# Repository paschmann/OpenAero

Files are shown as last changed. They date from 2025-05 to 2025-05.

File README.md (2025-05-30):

# OpenAero - A Open Source 3D-Printed Bicycle Accessory Mounting System

## Overview

The goal is to develop a modular mounting system for bicycle accessories — ranging from water bottle holders and lights to phone and cycling computers. Partially inspired by Gridfinity, this system provides a base platform and is intended to be stackable. The motivation behind the definition and open source nature of this project is to encourage community-driven design and innovation in the triathlon, and cycling space.

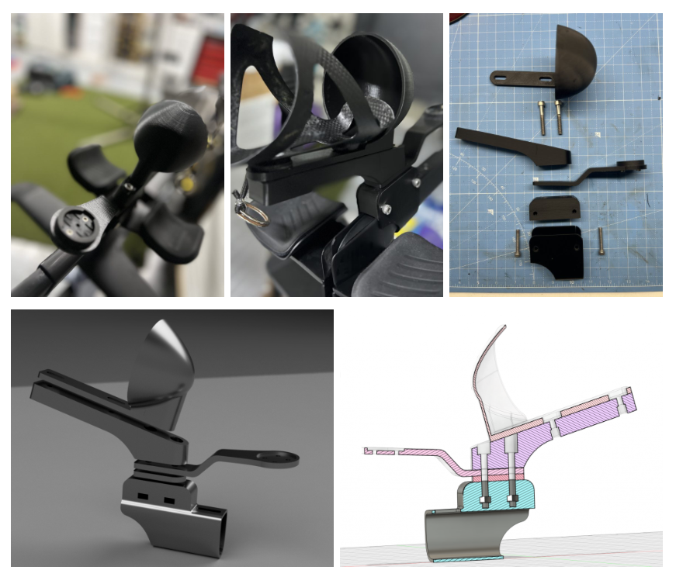
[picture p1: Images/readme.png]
Grid


### Concept

The fundamental concept is to create both specific and generic base mounts per bicycle model, whereby accessories can then be attached to the base mount using a standard pattern and design allowing you to mix and match your accessory "stack" depending on your needs. Accessories are not specific to a bike or model and are rather modular, and depend on your set of requirements.

A base mount could be the seat post, handlebars, aerobars, frame or bottle cage.

### Design

Standard

Standardized rectangular base mounting system of 21mm x 47mm with two M6 bolt pattern 25mm apart in the center. 

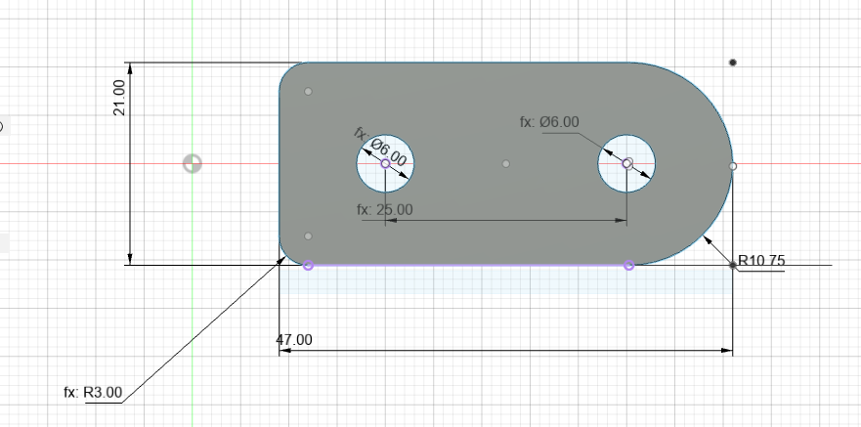
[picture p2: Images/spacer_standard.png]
Spacer


Small

A small rectangular base mounting system of 12mm x 23.5mm with one M5 bolt in the center. 

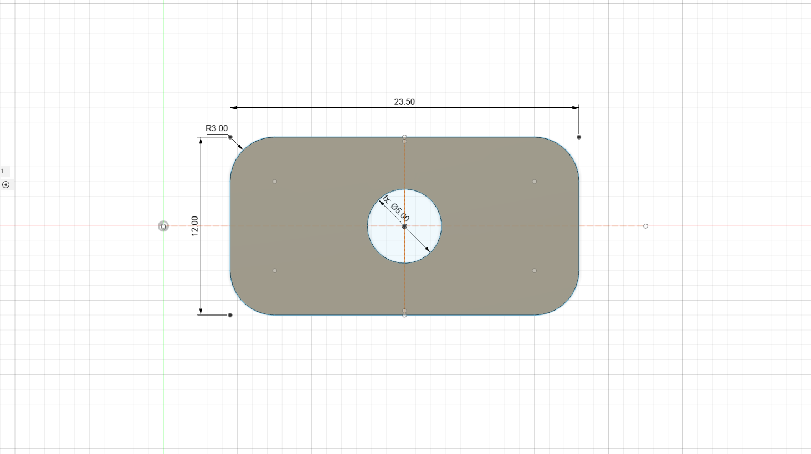
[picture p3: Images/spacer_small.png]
Spacer


### Printing

All bases and parts are intended to be 3D printed (many require supports), and most components require mounting hardware to be installed after printing is complete and is fairly straight forward. In all cases we recommend stainless steel, using locknut (blue) and torquing according to your manufacturers recommendations, especially when mounting the base or accessories to carbon fiber.

### Installation

In order to calculate the bolt lengths required, add up each accessories "Bolt Depth Required" on the accessories readme page.

Example:
You would like to mount a water bottle and computer mount on a Canyon Speedmax CF SLX.

Step 1. Select the Bike Mount required
Canyon Speedmax CF SLX Slide v1 - Bolt Depth Required: 12.5mm

Step 2. Select the bottle mount required
Bottle - Bolt Depth Required: 12.5mm

Step 3. Select the computer mount required
Computer Mount - Bolt Depth Required: 5mm

Step 4. Measure the height of your M6 bolt you purchased
Bolt - +- 5mm

Total bolt length: 35mm

Extremely important: ALWAYS assemble the base and accessories before installing them on your bike, to ensure no bolts or hardware will scratch or protrude into your bike frame or mounting hardware.

### ⚠️ Risk Disclaimer
This project and its associated files are provided for informational and non-commercial purposes only. All components are intended for mounting lightweight bicycle accessories only (e.g., lights, bottles, small electronics). These parts are not designed, tested, or approved for any load-bearing or safety-critical applications involving human weight or structural support.

By using or modifying these designs, you agree to assume all risks and responsibilities. The developer(s) and contributors are not liable for any injury, damage, or loss arising from the use or misuse of these components.

Always use common sense and test parts thoroughly in safe conditions before deploying them on a bicycle.

## Want to help?

Read our [Contributing Guide](CONTRIBUTING.md)

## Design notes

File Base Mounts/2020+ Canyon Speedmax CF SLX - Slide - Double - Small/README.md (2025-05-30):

# 2020+ Canyon Speedmax CF SLX - Slide Double Sided - Small v1

## Overview

Provides a base mount for a the Canyon GP0226 Aerobar and can be installed by disassembling the aerobars, this is relatively easy if you are using wireless blips. The accepts two small accessories such as computer mounts or a GoPro. Untested with water bottles, etc.

### Design Model
Bike used to design the part: 2025 Canyon Speedmax CF SLX

### Specs
Height: 63mm
Width: 27mm
Length: 55mm

### Accessory Mount Specs
Base Mount: 12mm x 23.5mm (Small)
Bolt Depth Required: 6mm

### Hardware Required

1 x 20mm M4 Hex Bolt (Button head suggested)
1 x ~ 4mm M4 Washer

### Installation Notes

This version of the Bike Mount is slide based which implies you need to remove the Speedmax extensions, and reuse of the existing mount holes with a new longer bolt.

NB: Be sure that the accessory bolts do not protrude through the base and come into contact of your bars.

### Design

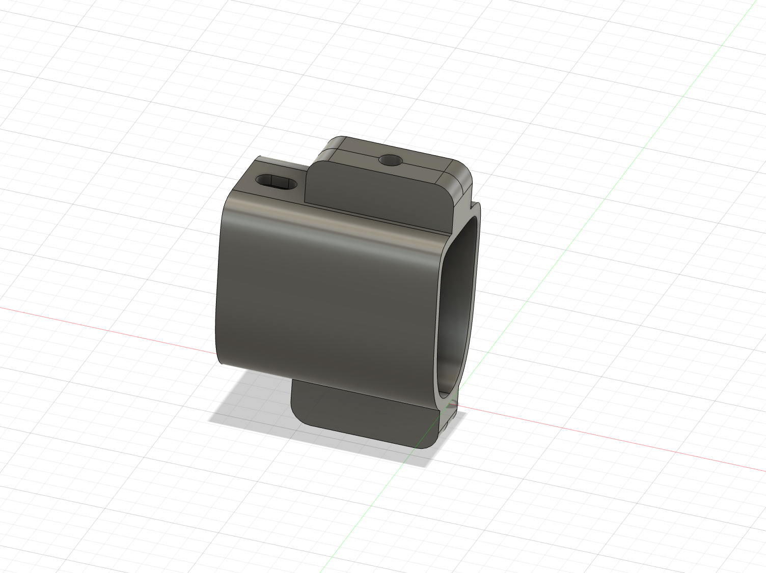
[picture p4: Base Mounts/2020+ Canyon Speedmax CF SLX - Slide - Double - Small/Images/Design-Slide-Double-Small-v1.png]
Design Screenshot


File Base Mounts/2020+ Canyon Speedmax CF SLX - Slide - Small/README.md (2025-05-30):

# 2020+ Canyon Speedmax CF SLX - Slide Small v1

## Overview

Provides a base mount for a the Canyon GP0226 Aerobar and can be installed by disassembling the aerobars, this is relatively easy if you are using wireless blips. The accepts small accessories such as computer mounts or a GoPro. Untested with water bottles, etc.

### Design Model
Bike used to design the part: 2025 Canyon Speedmax CF SLX

### Specs
Height: 57mm
Width: 27mm
Length: 55mm

### Accessory Mount Specs
Base Mount: 12mm x 23.5mm (Small)
Bolt Depth Required: 6mm

### Hardware Required

1 x 20mm M4 Hex Bolt (Button head suggested)
1 x ~ 4mm M4 Washer

### Installation Notes

This version of the Bike Mount is slide based which implies you need to remove the Speedmax extensions, and reuse of the existing mount holes with a new longer bolt.

NB: Be sure that the accessory bolts do not protrude through the base and come into contact of your bars.

### Design

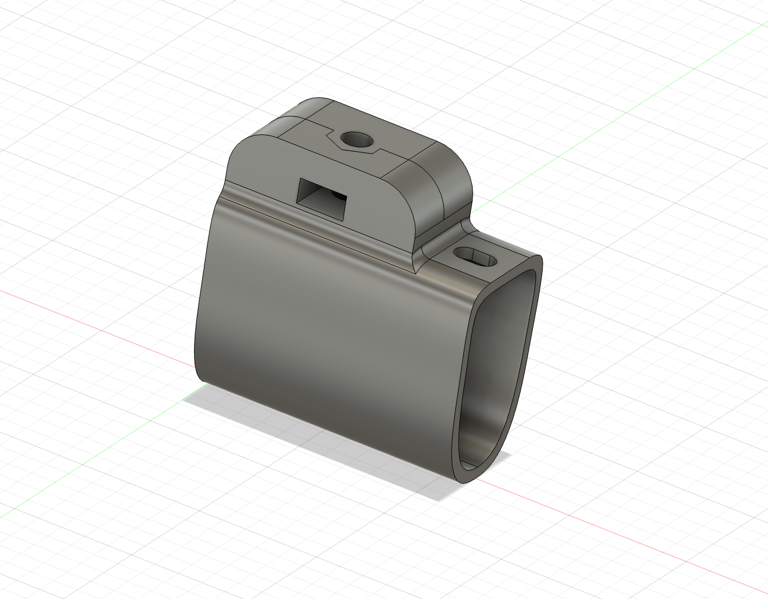
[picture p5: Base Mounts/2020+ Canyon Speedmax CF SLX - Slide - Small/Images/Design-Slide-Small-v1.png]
Design Screenshot


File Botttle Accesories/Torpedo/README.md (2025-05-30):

# Computer Mount

## Overview

Provides a torpedo shaped bottle cover for the OpenAero system, this is intended to provide a aerodynamic benefit for a water bottle between your arms.

### Specs
Height: 5mm\
Total Height: ~ 29mm\
Width: ~ 38mm\
Length: 148mm

### Accessory Mount Spec
Base Mount: Standard Bottle Cage
Bolt Length Required: 5mm

### Hardware Required

None

Note: Your water bottle cage bolts should be long enough to extend through this base which is 5mm thick.

### Installation Notes

Provides some adjustability (+- 10mm) to slide forward and backward to cater for various bottle cages.

### Design

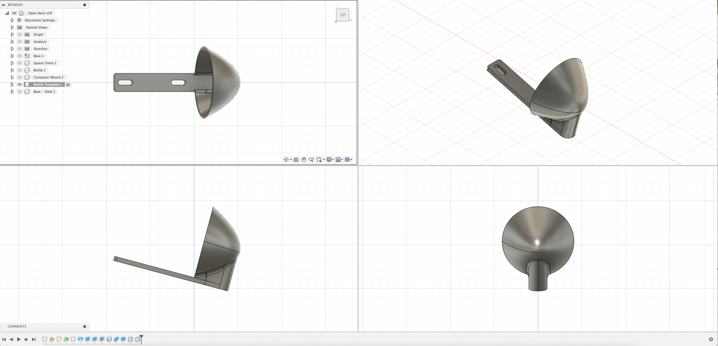
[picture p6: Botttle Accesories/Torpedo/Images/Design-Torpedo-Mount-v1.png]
Design Screenshot


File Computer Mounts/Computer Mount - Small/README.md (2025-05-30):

# Computer Mount - Small

## Overview

Provides a computer mount for the OpenAero system, and is raised slightly to provide access to any mounting or holes beneath the accessory. Requires a computer mount insert to be printed or purchased.

### Specs
Height: 5mm\
Total Height: ~ 36mm\
Width: ~ 36mm\
Length: 36mm

### Accessory Mount Spec
Base Mount: 12mm x 23.5mm (Small)\
Bolt Length Required: 10mm

### Hardware Required
1 x M5 Bolt
1 x Computer insert (e.g. Garmin, Wahoo, Hammerhead)\
2 x M3 bolts to attach computer insert onto accessory.\
2 x M3 Heat inserts (M3x5x6)

### Installation Notes

None

### Design

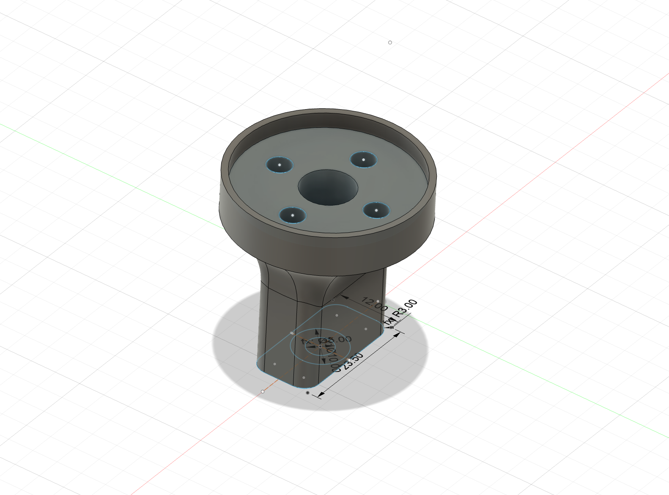
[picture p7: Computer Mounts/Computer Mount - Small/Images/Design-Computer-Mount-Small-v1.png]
Design Screenshot


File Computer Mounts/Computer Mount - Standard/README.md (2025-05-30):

# Computer Mount - Standard

 ### 🛑 Currently has an issue with being too flexible and could break quite easily. Currently being re-designed.

## Overview

Provides a computer mount for the OpenAero system, and is raised slightly to provide access to any mounting or holes beneath the accessory. Requires a computer mount insert to be printed or purchased.

### Specs
Height: 5mm\
Total Height: ~ 29mm\
Width: ~ 38mm\
Length: 148mm

### Accessory Mount Spec
Base Mount: 21mm x 47mm (Standard)\
Bolt Length Required: 5mm

### Hardware Required
1 x Computer insert (e.g. Garmin, Wahoo, Hammerhead)\
2 x M2 bolts to attach computer insert onto accessory.\

### Installation Notes

None

### Design

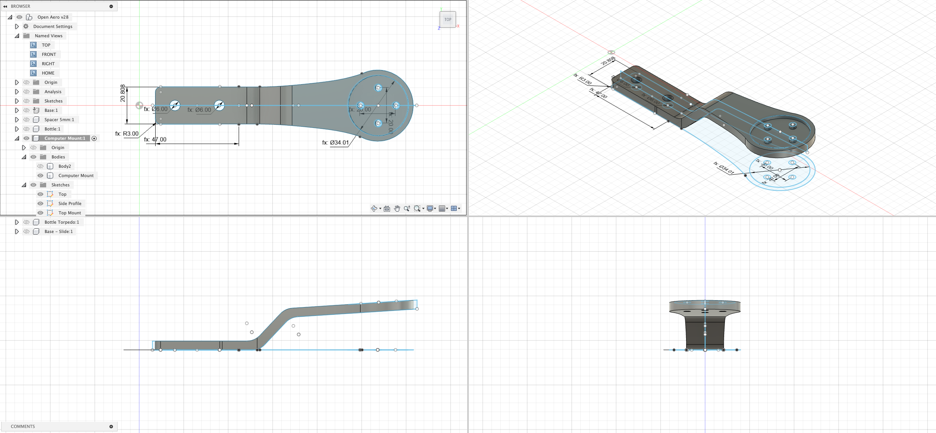
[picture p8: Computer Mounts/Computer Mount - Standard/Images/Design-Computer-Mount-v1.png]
Design Screenshot


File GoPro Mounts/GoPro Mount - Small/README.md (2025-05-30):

# GoPro Mount - Small

## Overview

Provides a small GoPro mount for the OpenAero system.

### Specs
Total Height: ~ 29mm\
Width: ~ 38mm\
Length: 148mm

### Accessory Mount Spec
Base Mount: 12mm x 32.5mm (Small)\
Bolt Length Required: 5mm

### Hardware Required
1 x M5 bolt
1 x M5 Nut

### Installation Notes

None

### Design

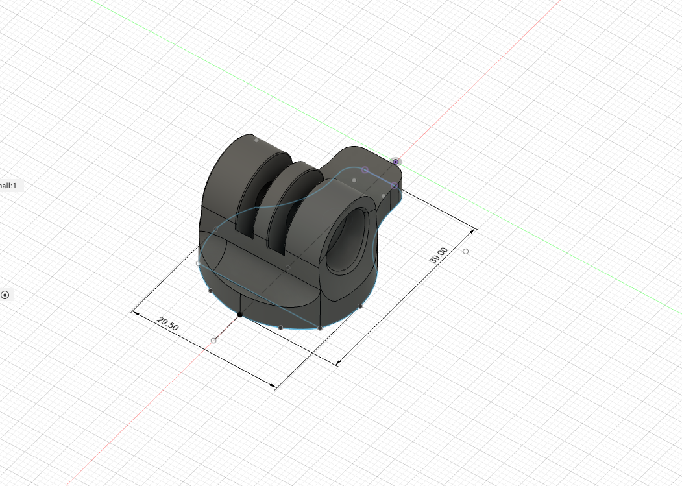
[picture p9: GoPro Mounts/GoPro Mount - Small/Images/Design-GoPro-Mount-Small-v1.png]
Design Screenshot


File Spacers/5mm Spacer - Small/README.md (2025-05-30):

# Spacer - 5mm - Small

## Overview

Provides a small 5mm spacer for the OpenAero design system, intended to raise the height of any accessory.

### Specs

Height: 5mm\
Width: 12mm\
Length: 32.5mm\

### Accessory Mount Spec

Base Mount: 12mm x 32.5mm (Small)\
Bolt Length Required: 5mm\

### Hardware Required
None

### Installation Notes
None

### Design
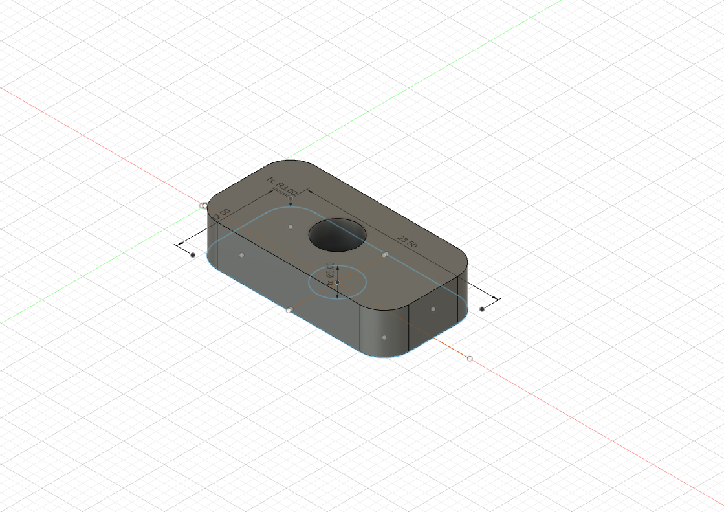
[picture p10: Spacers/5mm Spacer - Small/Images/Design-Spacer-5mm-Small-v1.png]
Design Screenshot


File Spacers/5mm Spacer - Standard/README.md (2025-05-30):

# Spacer - 5mm - Standard

## Overview

Provides a 5mm spacer for the OpenAero design system, intended to raise the height of any accessory.

### Specs

Height: 5mm\
Width: 21mm\
Length: 47mm\

### Accessory Mount Spec

Base Mount: 21mm x 47mm (Standard)\
Bolt Length Required: 5mm\

### Hardware Required
None

### Installation Notes
None

### Design
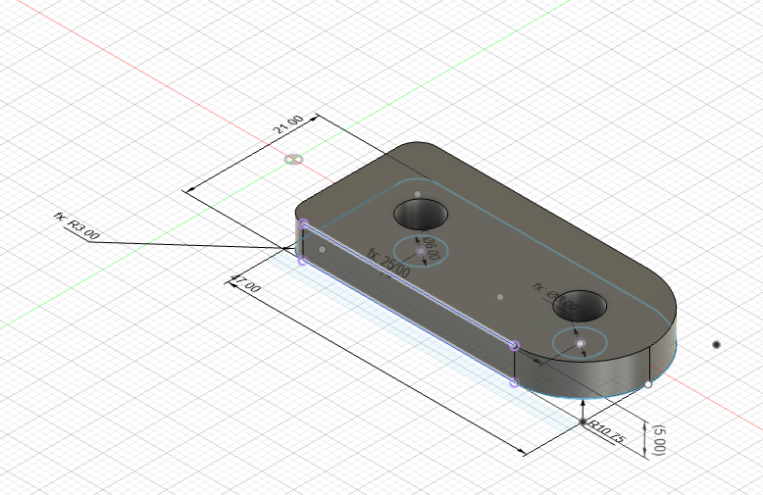
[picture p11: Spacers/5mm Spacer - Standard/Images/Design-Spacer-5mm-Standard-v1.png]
Design Screenshot


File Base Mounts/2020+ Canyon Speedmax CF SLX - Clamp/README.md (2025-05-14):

# 2020+ Canyon Speedmax CF SLX - Clamp Version 1

## Overview

Provides a base mount for a the Canyon GP0226 Aerobar and can be installed without disassembling the aerobars.

### Design Model
Bike used to design the part: 2025 Canyon Speedmax CF SLX

### Specs
Height: 24mm
Width:
Length:

### Accessory Mount Specs
Base Mount: 21mm x 47mm (Standard)
Bolt Depth Required: 12.5mm

### Hardware Required

2 x 30mm M5 Button Head Hex Bolt
2 x 3.8mm M5 Nuts

### Installation Notes

This version of the Bike Mount is clamp based which implies you do not need to remove the Speedmax extensions and can simply be bolted on. We recommend applying some tape to the mount area to improve grip and stability. Ne sure not to over tighten bolts (suggested torque, as for most carbon parts) is 5Nm.

NB: Be sure that the accessory bolts do not protrude through the base and come into contact of your bars.

### Design

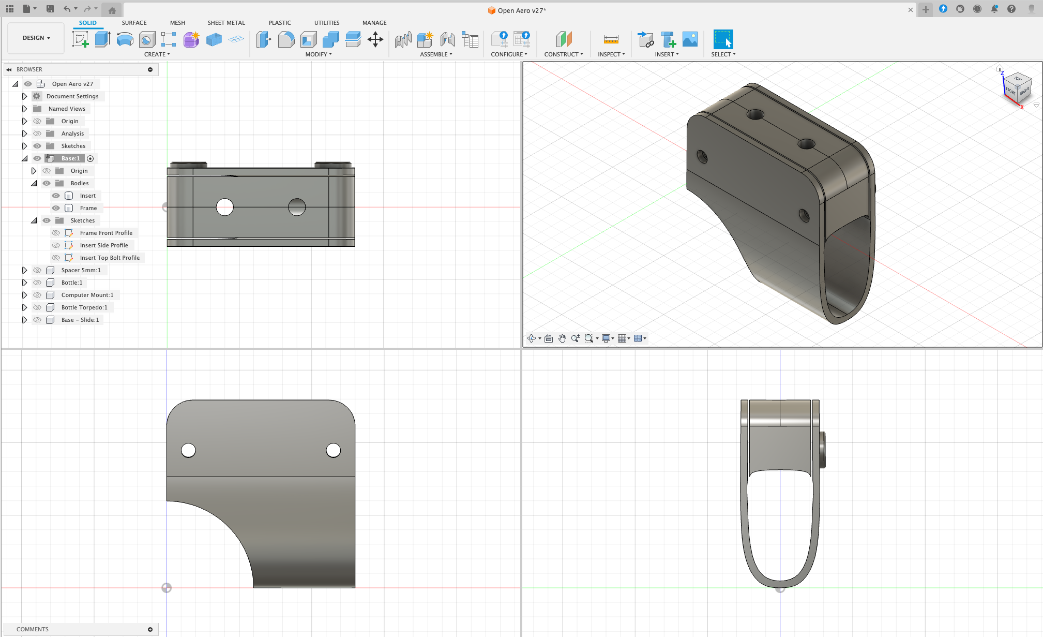
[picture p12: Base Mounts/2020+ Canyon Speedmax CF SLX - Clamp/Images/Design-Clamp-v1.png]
Design Screenshot


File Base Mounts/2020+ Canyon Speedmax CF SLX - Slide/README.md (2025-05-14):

# 2020+ Canyon Speedmax CF SLX - Slide Version 1

## Overview

Provides a base mount for a the Canyon GP0226 Aerobar and can be installed be disassembling the aerobars, this is relatively easy if you are using wireless blips. 

### Design Model
Bike used to design the part: 2025 Canyon Speedmax CF SLX

### Specs
Height: 24mm
Width:
Length:

### Accessory Mount Specs
Base Mount: (Standard) 21mm x 47mm
Bolt Depth Required: 12.5mm

### Hardware Required

1 x 20mm M4 Hex Bolt (Button head suggested)
1 x ~ 4mm M4 Washer

### Installation Notes

This version of the Bike Mount is slide based which implies you need to remove the Speedmax extensions, and reuse of the existing mount holes with a new longer bolt.

NB: Be sure that the accessory bolts do not protrude through the base and come into contact of your bars.

### Design

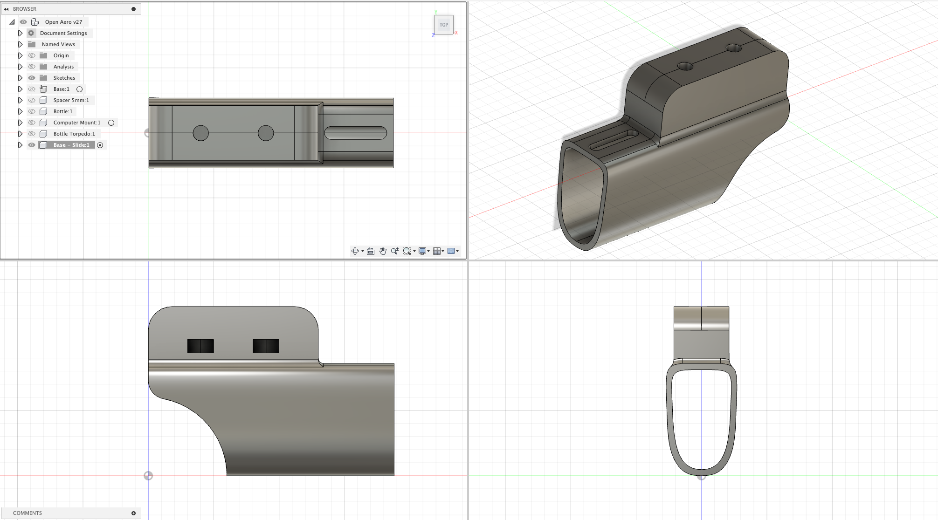
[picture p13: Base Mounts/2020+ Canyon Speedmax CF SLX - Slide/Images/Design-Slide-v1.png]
Design Screenshot


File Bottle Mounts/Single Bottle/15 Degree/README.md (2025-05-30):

# Single Bottle Mount - Standard

## Overview

Provides a single bottle mount for the OpenAero system.

### Specs
Height: 24mm
Width: 21mm
Length: 153mm
Angle: 15 Degrees

### Accessory Mount Spec
Base Mount: 21mm x 47mm (Standard)
Bolt Length Required: 12.5mm

### Hardware Required

2 x M6 Hex Bolts - The length of the bolts will depend on which accessories are stacked on top of each other.\
2 x M6 Nuts (~9.7mm Width)\
2 x M6 Washers (<= 13mm Diameter)

### Installation Notes

None

### Design

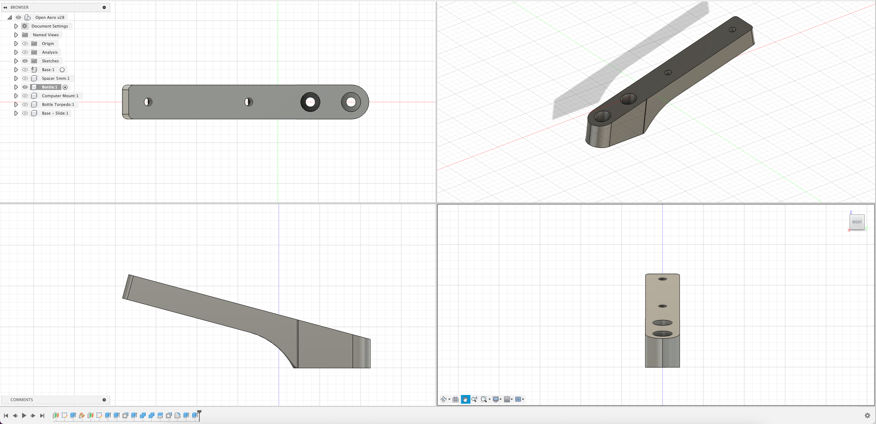
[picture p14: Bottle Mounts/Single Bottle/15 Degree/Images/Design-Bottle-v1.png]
Design Screenshot

Bottle Mount v1

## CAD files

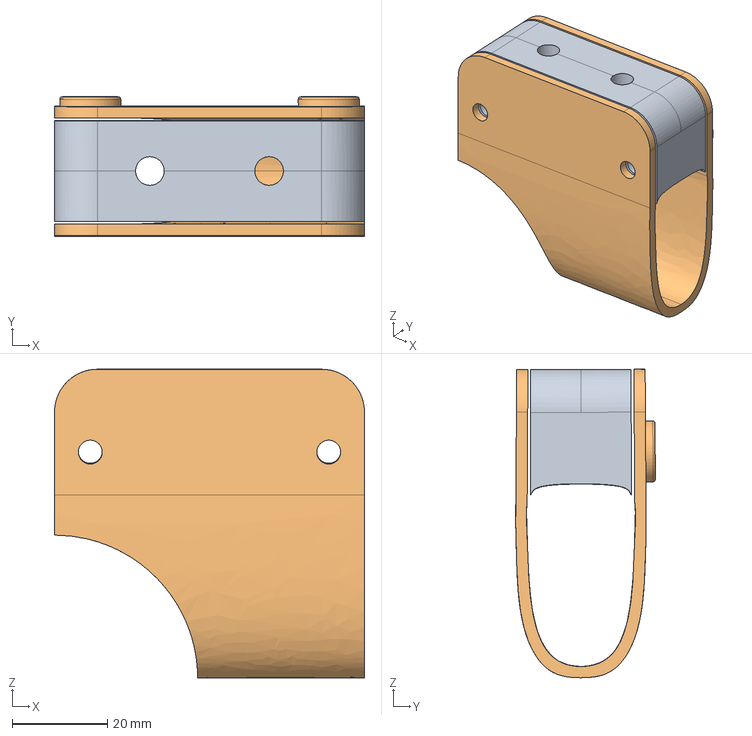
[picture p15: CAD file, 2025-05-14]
Base Mounts/2020+ Canyon Speedmax CF SLX - Clamp/Clamp Mount v1.step
65.0 x 29.3 x 64.7 mm

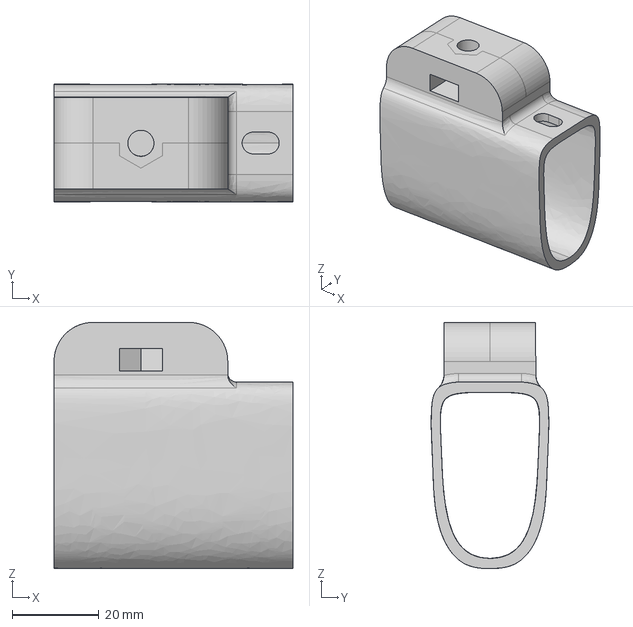
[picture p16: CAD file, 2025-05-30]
Base Mounts/2020+ Canyon Speedmax CF SLX - Slide - Double - Small/Slide Mount Small v1.step
55.0 x 27.1 x 56.7 mm

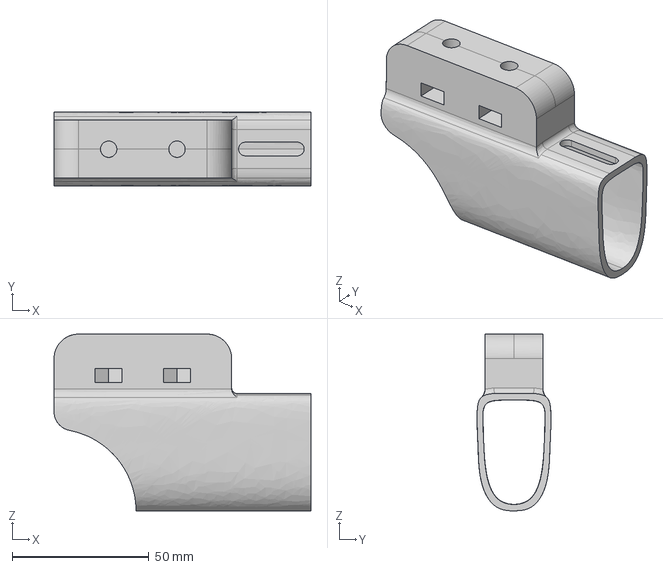
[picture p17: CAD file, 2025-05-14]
Base Mounts/2020+ Canyon Speedmax CF SLX - Slide/Slide Mount v1.step
94.0 x 27.1 x 64.7 mm

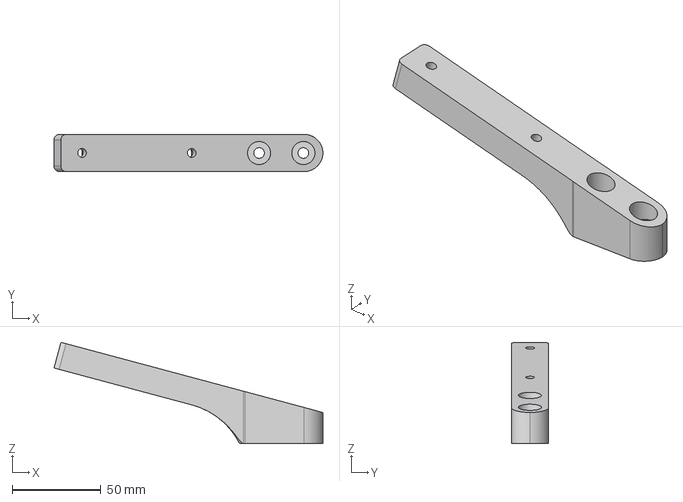
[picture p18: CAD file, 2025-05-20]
Bottle Mounts/Single Bottle/15 Degree/Bottle Mount v1.step
151.7 x 21.1 x 57.2 mm

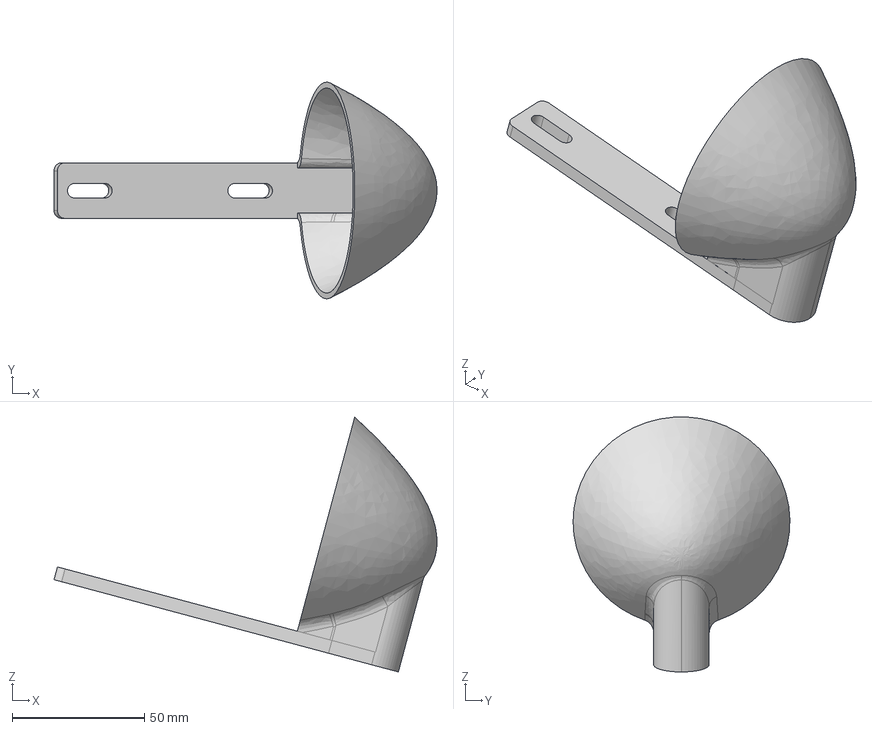
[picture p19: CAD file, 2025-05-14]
Botttle Accesories/Torpedo/Torpedo v1.step
144.8 x 82.0 x 96.4 mm

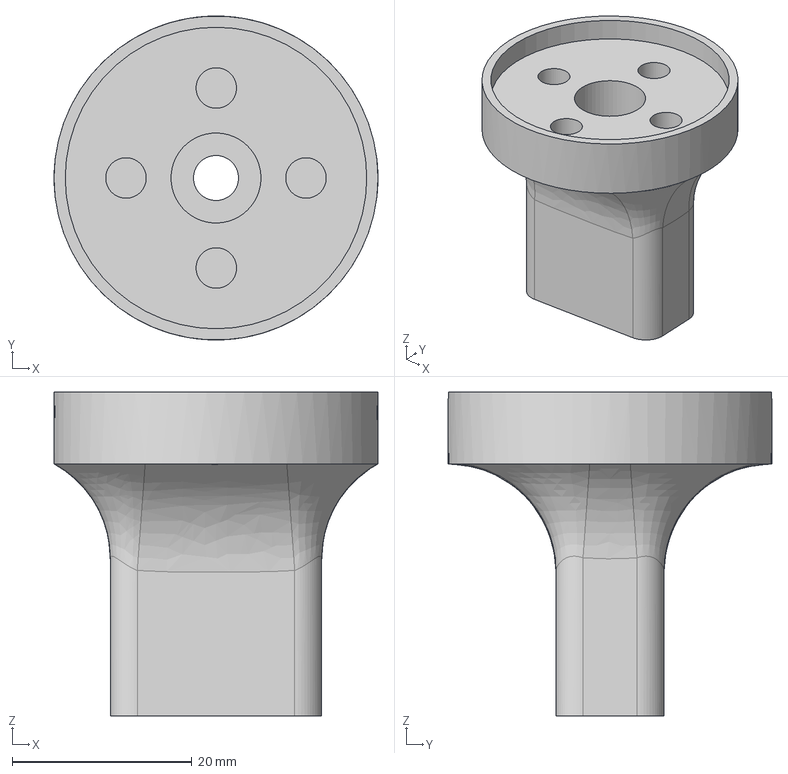
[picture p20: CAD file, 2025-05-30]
Computer Mounts/Computer Mount - Small/Computer Mount Small v1.step
36.0 x 36.0 x 36.0 mm

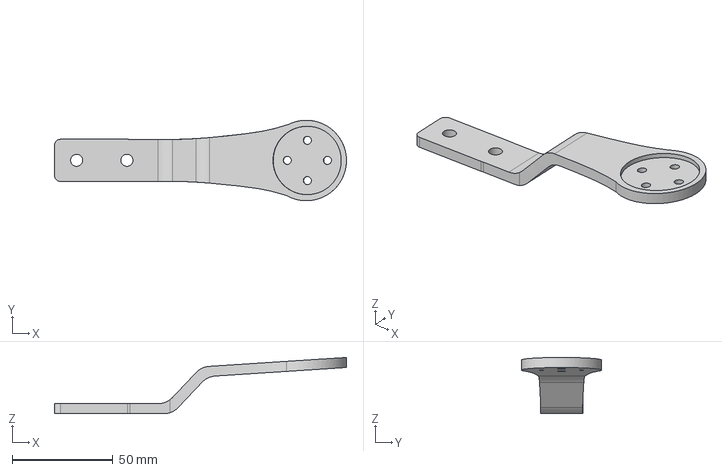
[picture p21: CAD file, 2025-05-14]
Computer Mounts/Computer Mount - Standard/Computer Mount Standard v1.step
145.1 x 40.0 x 27.9 mm

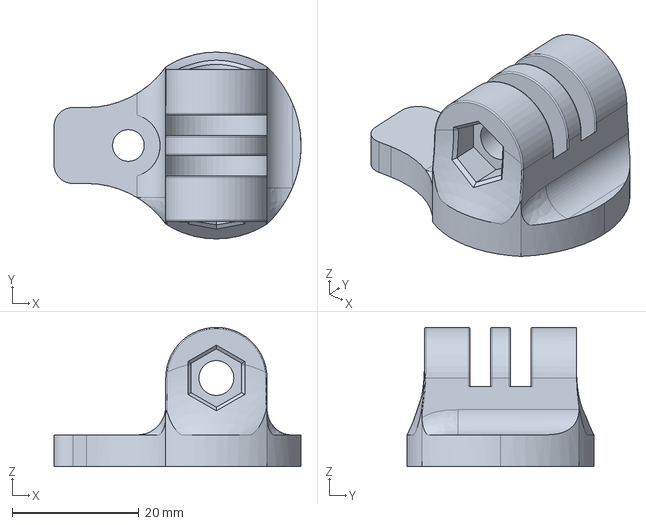
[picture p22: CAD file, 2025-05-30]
GoPro Mounts/GoPro Mount - Small/GoPro Mount Small v1.step
39.0 x 29.5 x 22.0 mm

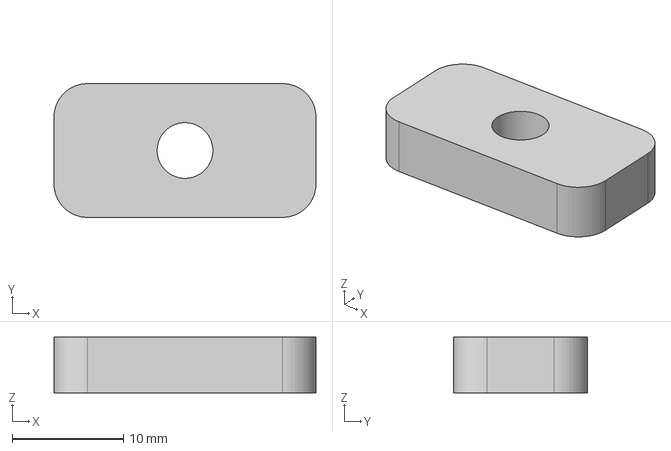
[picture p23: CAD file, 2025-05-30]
Spacers/5mm Spacer - Small/Spacer 5mm Small.step
23.5 x 12.0 x 5.00 mm

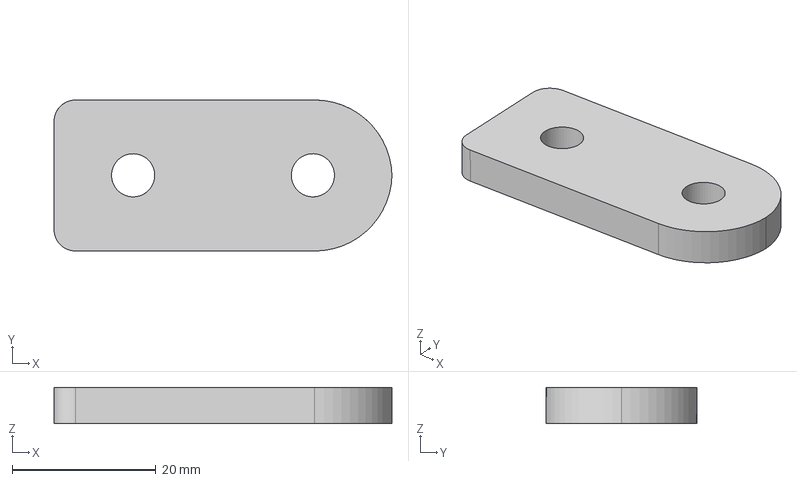
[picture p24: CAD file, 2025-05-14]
Spacers/5mm Spacer - Standard/Spacer 5mm.step
47.0 x 21.0 x 5.01 mm

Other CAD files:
Base Mounts/2020+ Canyon Speedmax CF SLX - Clamp/Clamp Mount v1.stl
Base Mounts/2020+ Canyon Speedmax CF SLX - Slide - Double - Small/Slide Mount Small v1.stl
Base Mounts/2020+ Canyon Speedmax CF SLX - Slide - Small/Slide Mount Small v1.stl
Base Mounts/2020+ Canyon Speedmax CF SLX - Slide/Slide Mount v1.stl
Bottle Mounts/Single Bottle/15 Degree/Bottle Mount v1.stl
Botttle Accesories/Torpedo/Torpedo v1.stl
Computer Mounts/Computer Mount - Small/Computer Mount Small v1.stl
Computer Mounts/Computer Mount - Standard/Computer Mount Standard v1.stl
GoPro Mounts/GoPro Mount - Small/GoPro Mount Small v1.stl
Spacers/5mm Spacer - Small/Spacer 5mm Small.stl
Spacers/5mm Spacer - Standard/Spacer 5mm.stl

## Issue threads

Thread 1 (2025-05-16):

Issue with Computer Mount

paschmann, 2025-05-16:
Broke on first ride, way too much flex. Either needs to be thicker base/frame or redesign.

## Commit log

2025-05-14 Initial Commit :)
    [Bottle Mount v1.step, Bottle Mount v1.stl, Clamp Mount v1.step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]
2025-05-14 - File changes and restructuring
    [Bottle Mount v1.step, Bottle Mount v1.stl, Spacer 5mm.step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]
2025-05-14 - Add comment for cage bolt length
2025-05-20 - Increases washer size of M6 as the current design was too small (12mm -> 13mm)
    [Bottle Mount v1.step, Bottle Mount v1.stl]
2025-05-30 - Add a Small Computer Mount - Add a Small GoPro Mount - Add a Small 5mm Spacer - Add a Speedmax Small Base - Add a Speedmax Small Double Sided Base - Updated documentation
    [Computer Mount Small v1.step, Computer Mount Small v1.stl, Computer Mount Standard v1.step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]
